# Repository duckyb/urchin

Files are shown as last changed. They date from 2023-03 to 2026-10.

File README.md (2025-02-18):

# Urchin 🪸

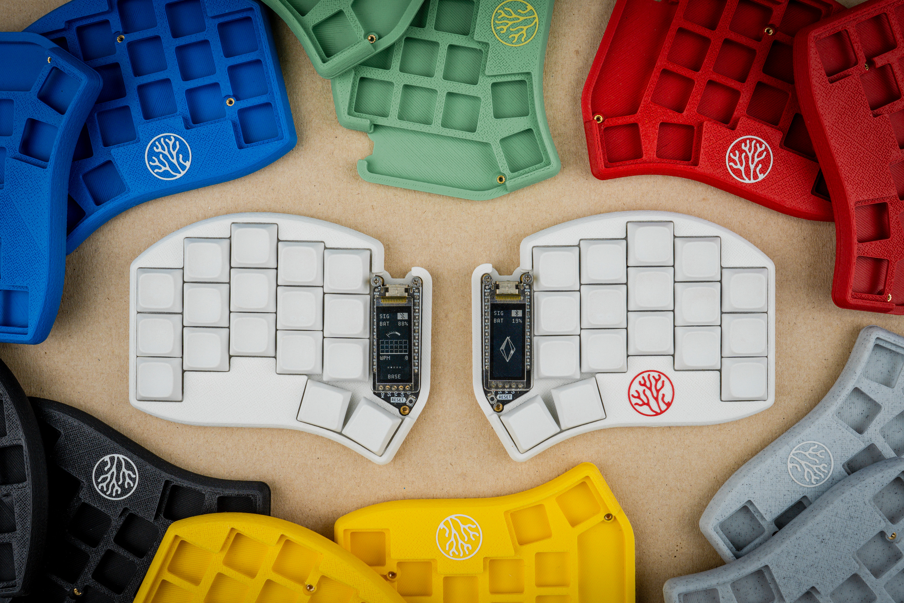
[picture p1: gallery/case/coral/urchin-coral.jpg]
Showcase Picture


<span>
  
  <a href="https://github.com/duckyb/urchin/releases">
    
    
  </a>
  
  <br/>
  <a href="https://discord.gg/hAm5QVJrbU">
    
  </a>
</span>

I created this design because I wanted to upgrade my [Sweep](https://github.com/davidphilipbarr/Sweep) with the fancy nice!view displays. I decided to use the edge design from the [Swoop](https://github.com/jimmerricks/swoop) and to make it compatible with Kailh hotswap sockets.
**This is a strictly wireless-only design, and is only compatible with ZMK / nice!nano. Only Choc v1 switches + Hotswap are supported!**

> Q: Why is this not just another Sweep?
> _A: In order to support the nice!view display I had to use a switch matrix with diodes instead of the Sweep's direct pin design. This means that the firmwares are not interchangeable. I also wanted to use a different PCB shape which makes it incompatible with Sweep cases._

**If you enjoy my work, please consider ⭐ starring and/or ❤ sponsoring it.**

## Sponsors

_Support the people that support me!_ 🙏🏻

<span class="sponsors">
  <a href="https://www.pcbway.com/">
    
  </a>
  <a href="https://shop.beekeeb.com/">
    
  </a>
</span>

## Features

- [x] Design fully optimized for wireless
- [x] Native nice!view support
- [x] Familiar Ferris/Sweep layout
- [x] Improved outline shape
- [x] Support for Kailh hotswap sockets
- [x] Mounting points for cases
- [x] 3D printable enclosure case
- [x] Switch Plate files (3 options)
- [x] MCU/Screen Cover files

## Part list (for a full keyboard)

#### Required

- 1× PCB Kit (files for it are in [releases](https://github.com/duckyb/urchin/releases))
- 34× Kailh **CHOC** Hotswap Sockets
- 34× Kailh Choc v1 Switches
- 34× Keycaps
- 34× SMD diodes (SOD-123)
- 2× nice!nano
- 2× Lipo battery (301230)
- 48× mill-max machined pins
- 2× Pair of female headers

#### Optional

- 2× nice!view
- 2× Reset switch (B3U-1000P(M))
- 2× Power switch (MSK 12C02)
- 10× adhesive silicone feet

#### Case (NEW!)

| Coral Case | Description |
| --- | --- |
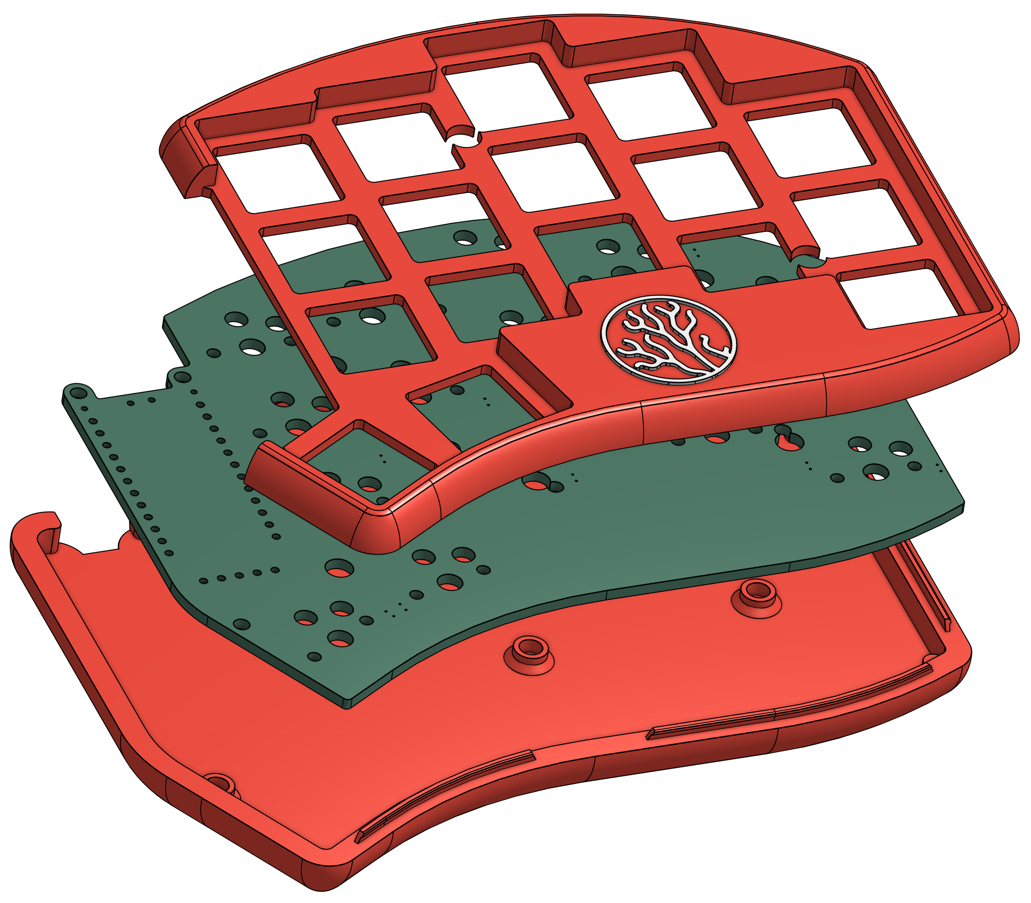
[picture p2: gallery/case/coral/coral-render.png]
Coral Case
|  | The official Coral case is available on [Makerworld](https://makerworld.com/en/models/1057239#profileId-1044921) (for free). Other cases can be found in this repository inside the `3d-prints` folder. |

> [!NOTE]  
> Installing a case, microcontroller cover, or screen acrylic cover will require additional M2 hardware not included in this list. (Like screws, standoffs, nuts, heat set inserts)

## How do I make this?

<a href="https://youtu.be/CHSh1-dJq24" target="_blank">

</a>

## Firmware

Urchin supports ZMK only. To get started with ZMK visit the [zmk-urchin repository](https://github.com/duckyb/zmk-urchin) and follow the provided instructions.

## More videos about Urchin

- https://www.youtube.com/watch?v=o2W_uG-OBjk

## Credits

- PCB edge design by [jimmerricks](https://github.com/jimmerricks/swoop)
- Coral, rocks, sand & bubbles by [Kneecrust](https://linktr.ee/kneecrust)
- The development name "Swipe Light" by [Pete](https://github.com/petejohanson)
- Nice!view integration reference: [sadekbaroudi/sweep36](https://github.com/sadekbaroudi/sweep36)
- ZMK Firmware help by [Mabroum](https://github.com/AlaaSaadAbdo) & [Bravekarma](https://github.com/caksoylar)
- Silkscreen labels style: [bastardkb/dilemma](https://github.com/Bastardkb/Dilemma)
- 3d case by [iamDrakkir](https://github.com/iamDrakkir)
- 3d case by [chewiedies](https://www.printables.com/it/social/360738-chewiedies/about)
- 3d case by [carrefinho](https://github.com/carrefinho)
- Coral logo idea by exosr on discord

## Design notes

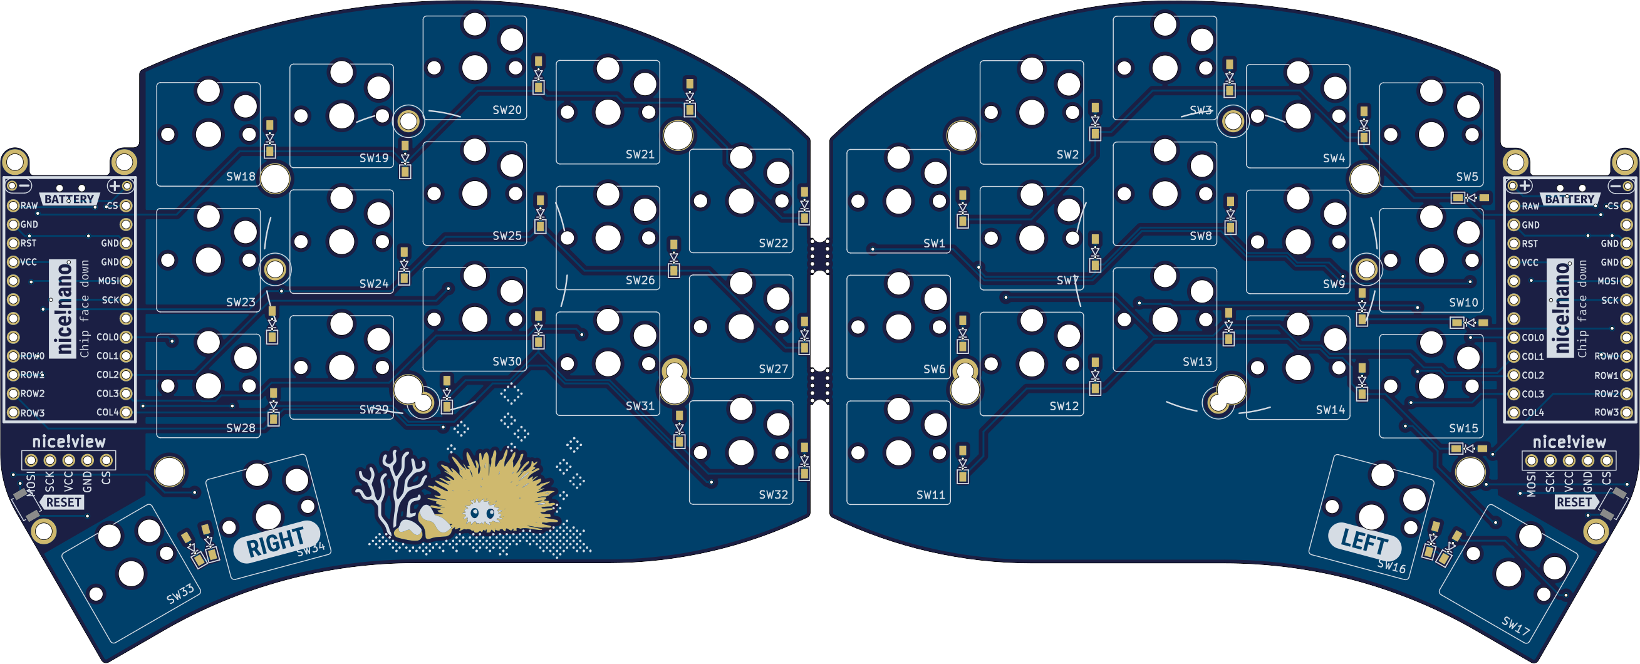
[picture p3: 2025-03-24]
gallery/main/main-top.png

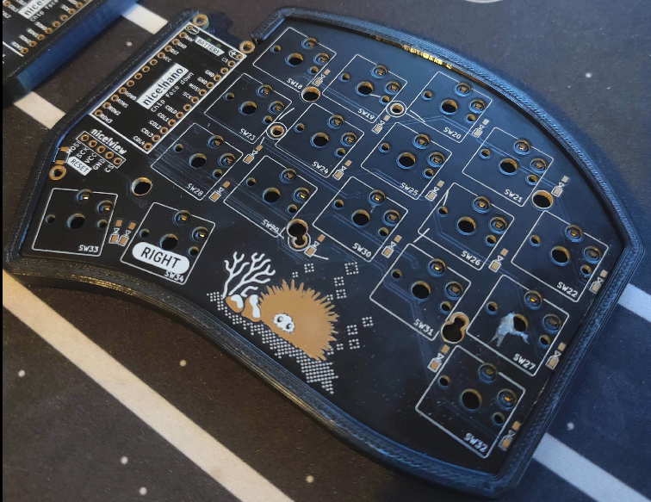
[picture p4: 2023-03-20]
gallery/case/iamDrakkir/rl-side.png

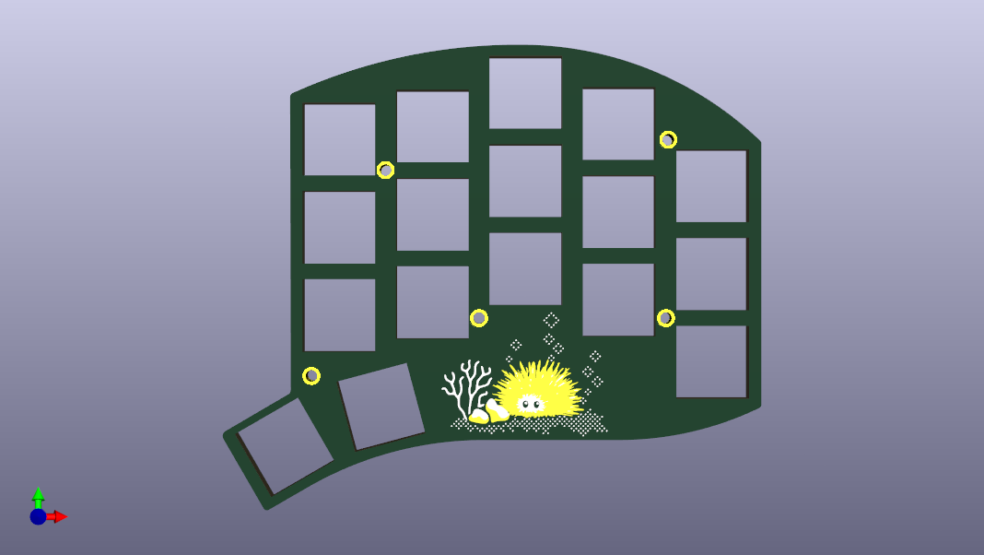
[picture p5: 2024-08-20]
gallery/plate/switch-plate.png

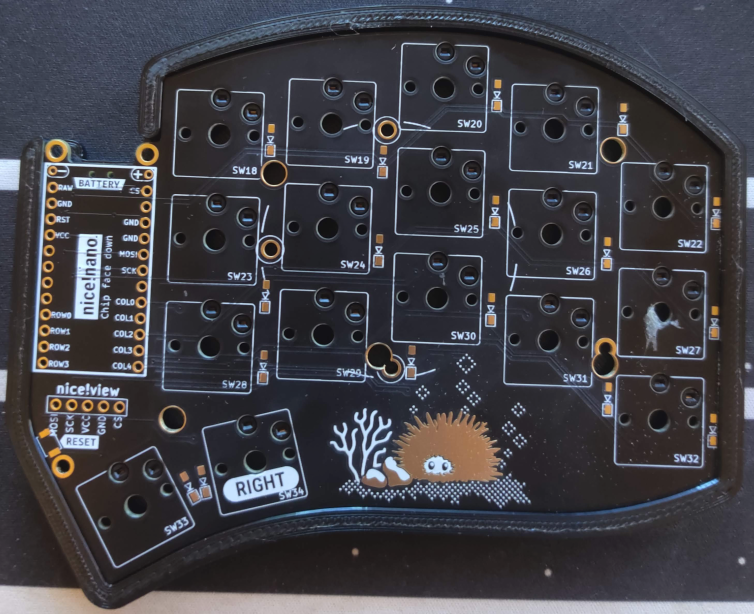
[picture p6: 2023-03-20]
gallery/case/iamDrakkir/rl-top.png

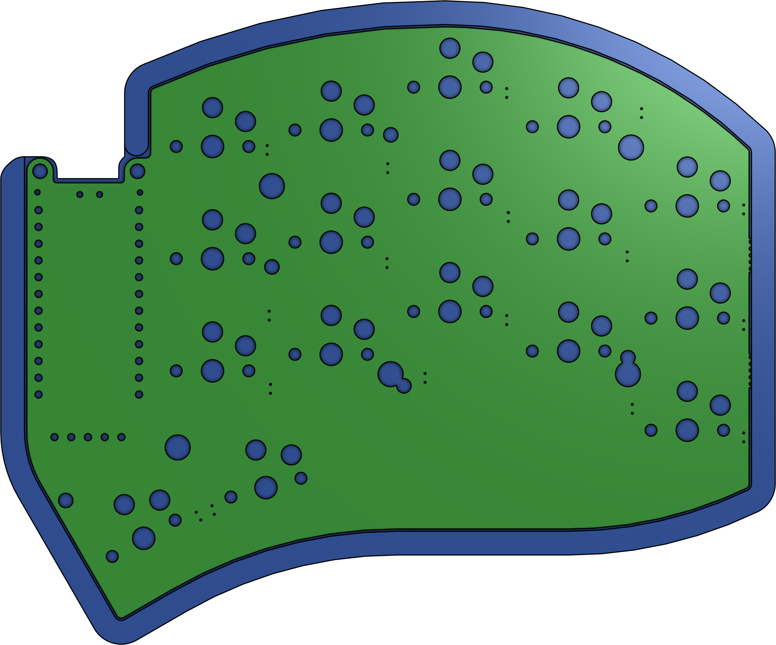
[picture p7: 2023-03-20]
gallery/case/iamDrakkir/cad-top-pcb.png

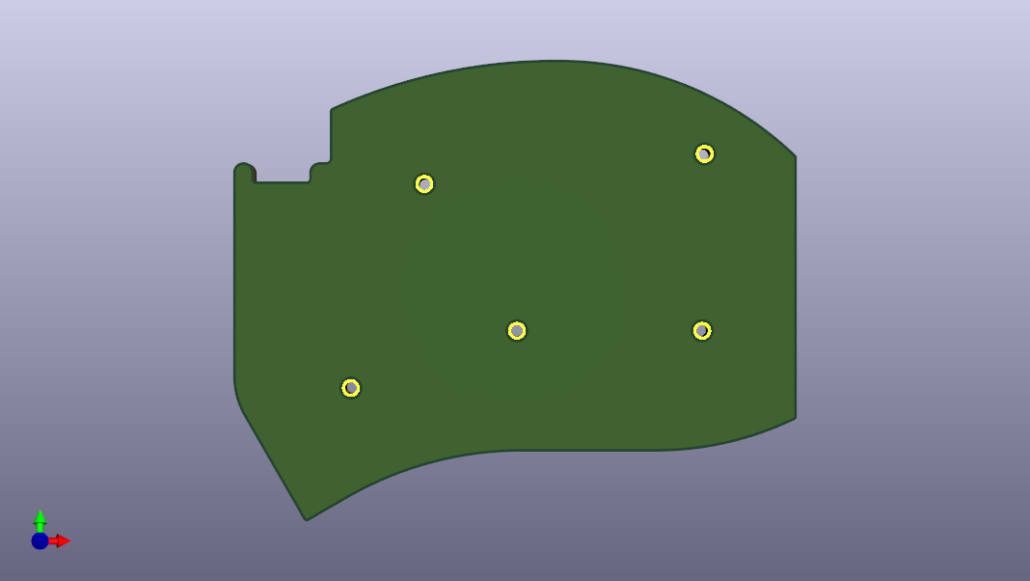
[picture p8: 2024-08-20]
gallery/plate/base-plate.png

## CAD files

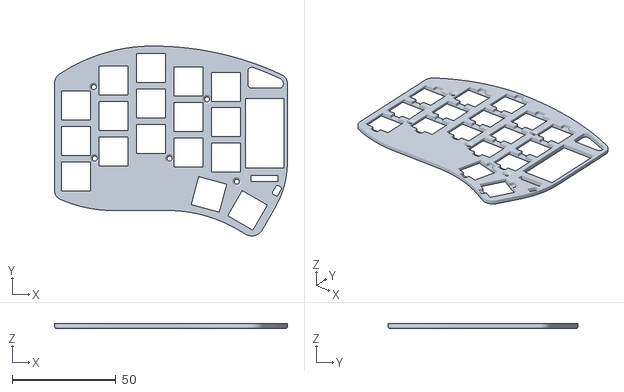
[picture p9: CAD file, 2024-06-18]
3d-prints/case-by-carrefino/urchin_plate_left_full.stl
112.0 x 91.3 x 2.20

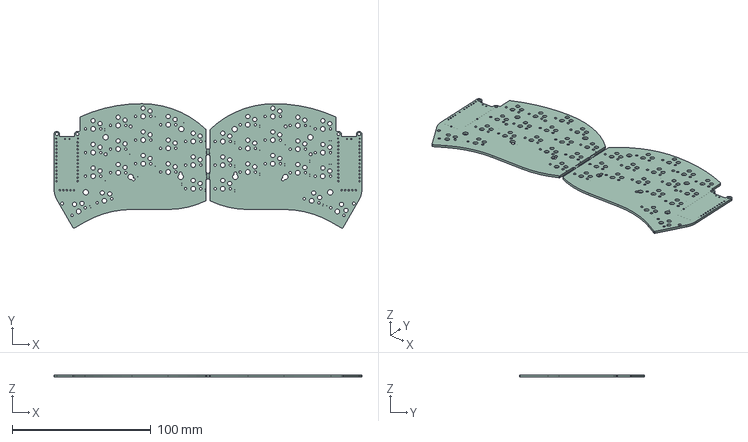
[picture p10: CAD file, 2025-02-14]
main.step
221.6 x 89.6 x 1.60 mm

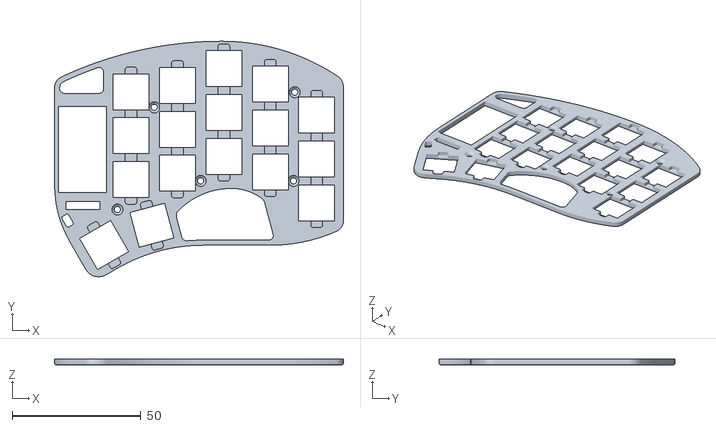
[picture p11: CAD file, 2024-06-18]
3d-prints/case-by-carrefino/urchin_plate_right_full.stl
112.0 x 91.3 x 2.20

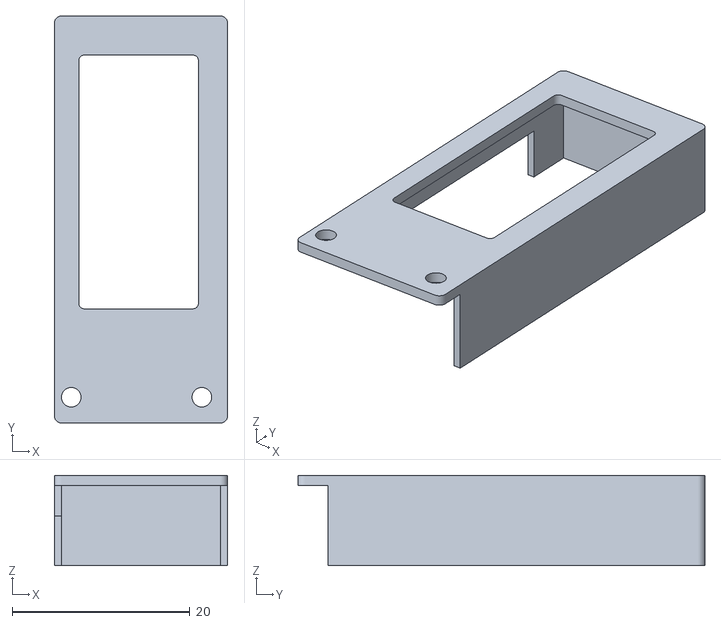
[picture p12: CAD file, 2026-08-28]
3d-prints/boxy-case-by-rayreside/urchin_boxy_shield_right.stl
19.5 x 45.8 x 10.2

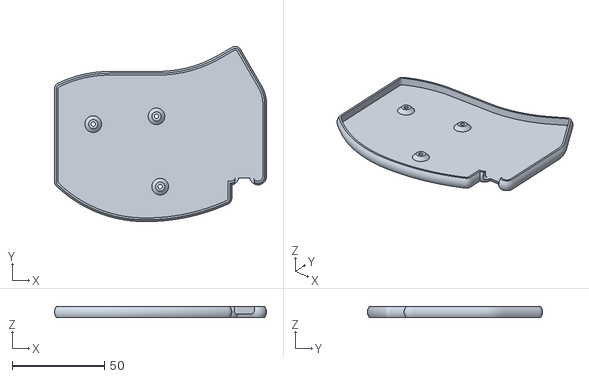
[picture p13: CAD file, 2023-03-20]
3d-prints/case-by-chewiedies/v1-TrayWithFillet-capture.stl
114.7 x 94.8 x 6.00

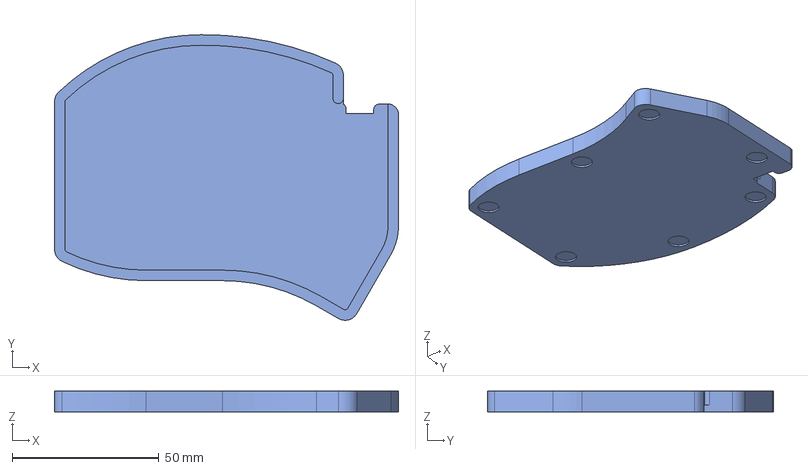
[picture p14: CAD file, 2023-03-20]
3d-prints/case-by-iamDrakkir/case-right.step
117.3 x 97.4 x 7.00 mm

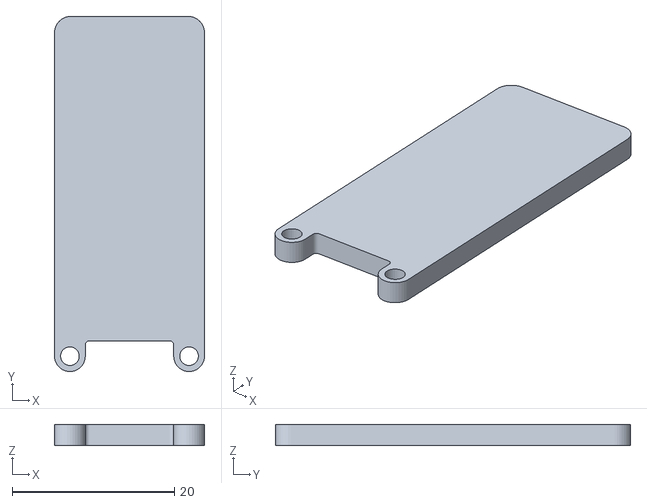
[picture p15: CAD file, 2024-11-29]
3d-prints/screen-shield/screen-shield.stl
18.5 x 43.8 x 2.60

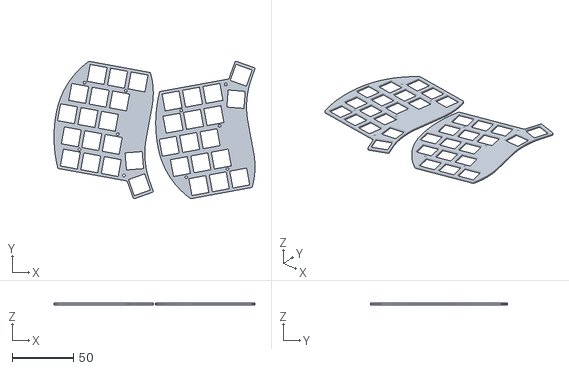
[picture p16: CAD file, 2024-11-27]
3d-prints/switch-plate/standard__plate.stl
164.3 x 112.3 x 1.60

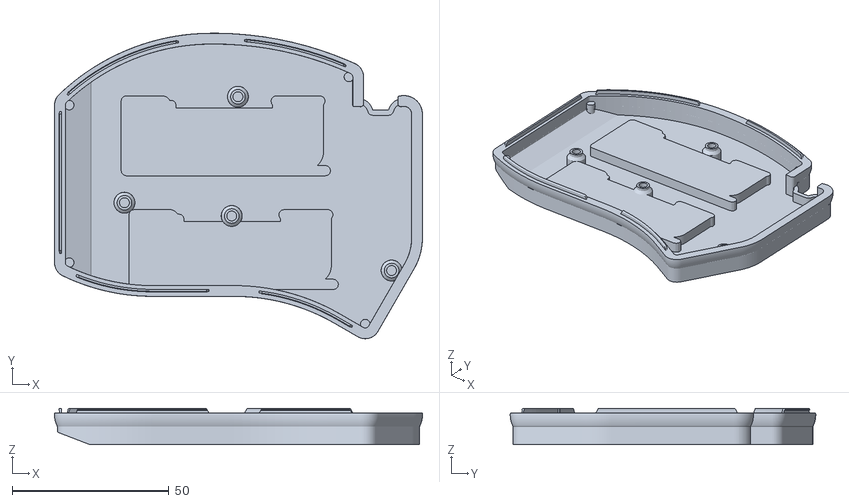
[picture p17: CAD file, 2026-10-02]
3d-prints/tenting-bottom-by-jadefalkner/urchin_tenting_bottom_left.stl
117.4 x 97.5 x 11.5

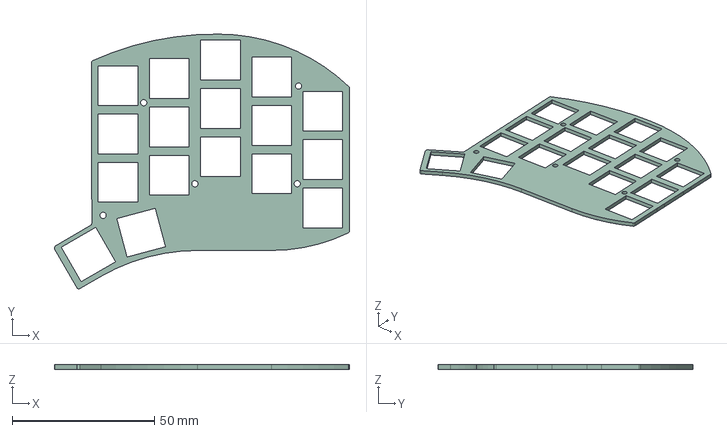
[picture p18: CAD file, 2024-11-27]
plate-case/switch-plate/switch-plate.step
103.7 x 89.6 x 1.60 mm

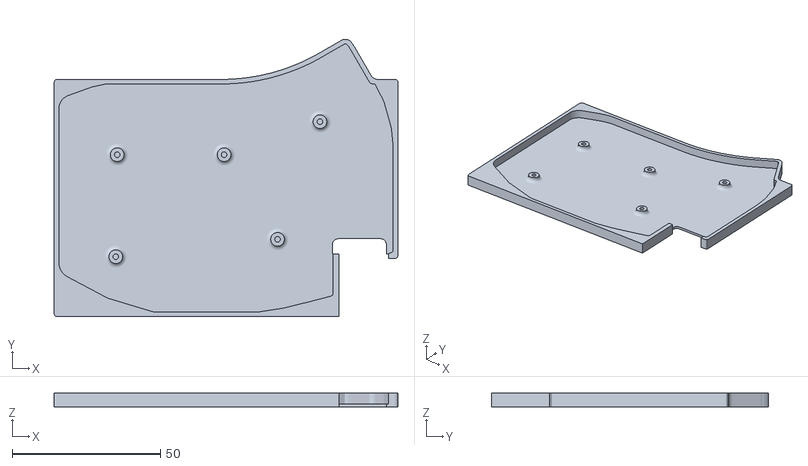
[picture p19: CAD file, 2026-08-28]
3d-prints/boxy-case-by-rayreside/urchin_boxy_bottom_right.stl
115.8 x 93.4 x 4.60

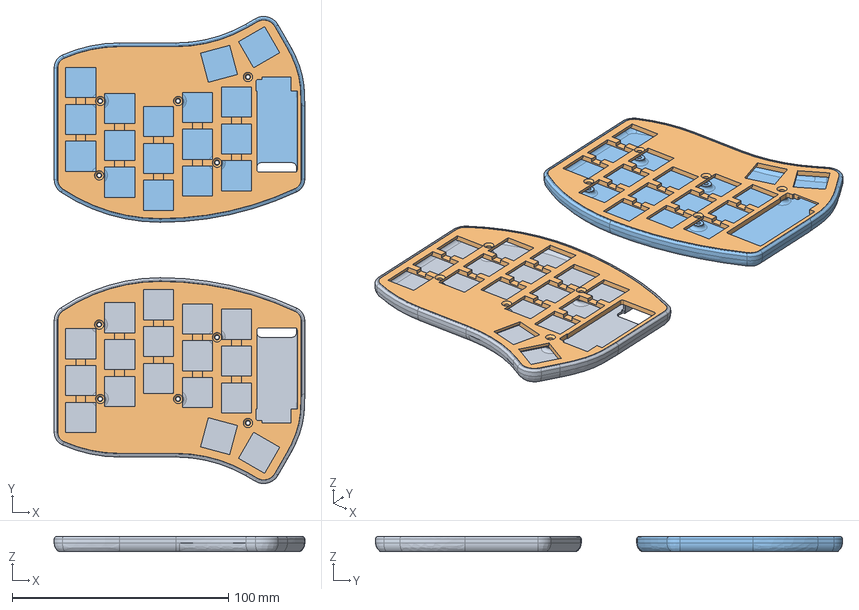
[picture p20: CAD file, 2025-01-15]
3d-prints/case-by-rayreside/case v8.step
115.8 x 215.8 x 6.80 mm

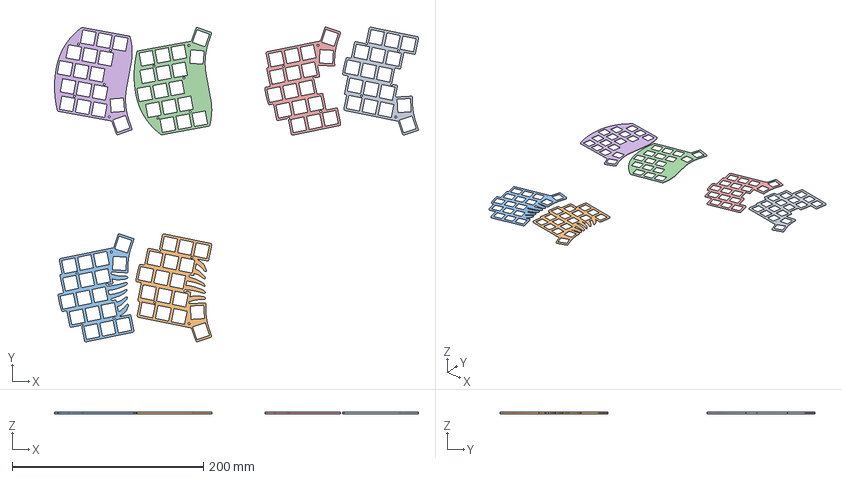
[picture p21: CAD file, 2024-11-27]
3d-prints/switch-plate/ALL-OPTIONS.3mf
380.3 x 329.0 x 1.60 mm
urchin-switch-plate.stl x 4
switch-plate.step x 2

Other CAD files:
3d-prints/case-by-rayreside/screen-shield v16.step
3d-prints/case-by-carrefino/urchin_plate_right_reset.stl
3d-prints/case-by-chewiedies/v1-TrayWithFillet-inserts.stl
3d-prints/case-by-iamDrakkir/case-left.step
3d-prints/tenting-bottom-by-jadefalkner/urchin_tenting_bottom_right.stl
3d-prints/boxy-case-by-rayreside/urchin_boxy_mountains_right.stl
3d-prints/boxy-case-by-rayreside/urchin_boxy_top_right.stl
3d-prints/case-by-carrefino/Urchin Plate Case.f3z
3d-prints/case-by-carrefino/Urchin Plate Case.step
3d-prints/case-by-carrefino/urchin_case_left.stl
3d-prints/case-by-carrefino/urchin_case_right.stl
3d-prints/case-by-carrefino/urchin_plate_left_basic.stl
3d-prints/case-by-carrefino/urchin_plate_left_reset.stl
3d-prints/case-by-carrefino/urchin_plate_right_basic.stl
3d-prints/case-by-chewiedies/Urchin_Tray_Case.f3d
3d-prints/case-by-chewiedies/v1-TrayWithChamfer-capture.stl
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

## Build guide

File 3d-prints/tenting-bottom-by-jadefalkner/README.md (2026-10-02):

# Urchin tenting bottom (TOTEM feet)

A replacement bottom for the official Coral case that takes the same tenting
feet as the TOTEM tenting case (the AliExpress feet from #23). The Coral top
is used unchanged. A 40 × 20 × 4 mm (350 mAh) battery fits next to the feet.

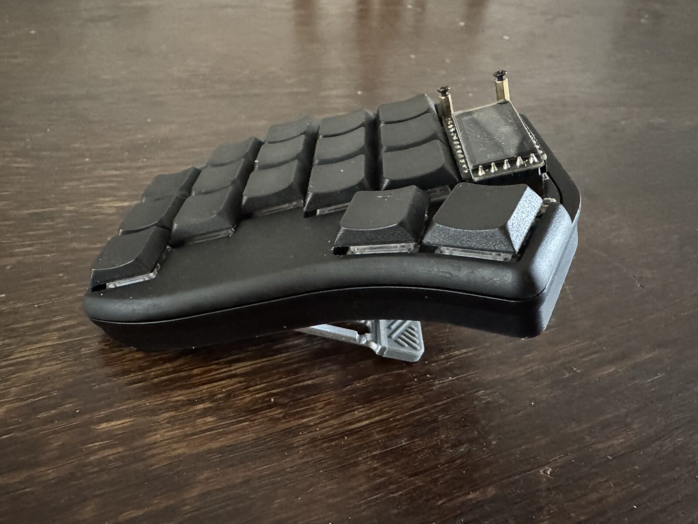
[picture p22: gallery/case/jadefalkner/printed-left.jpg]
Printed left half, tented


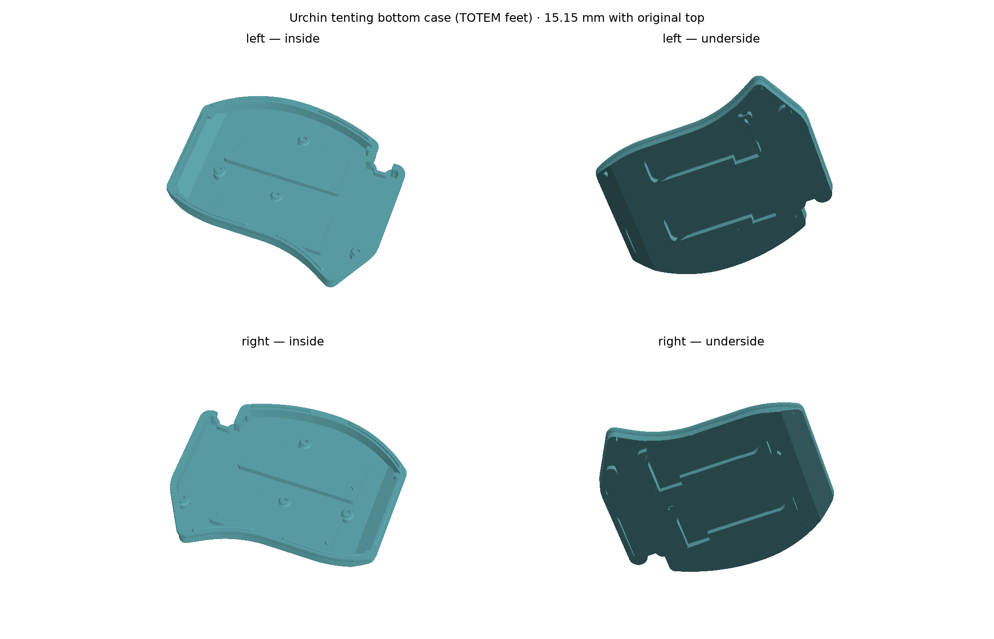
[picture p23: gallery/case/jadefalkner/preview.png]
Tenting bottom, inside and underside


## Parts

- `urchin_tenting_bottom_left.stl`
- `urchin_tenting_bottom_right.stl`

Each half has two foot pockets running east–west, so the halves tent towards
the middle. The right half is a mirror of the left, pockets included.

## Dimensions

- Bottom: 11.53 mm. With the Coral top: 15.15 mm (without feet, switches and keycaps).
- Floor 2 mm. Foot pockets 4.1 mm deep, roofed with 1.65 mm at the height of
  the original inner floor, so the electronics clearance is the same as in the
  original bottom.
- Outer bearing chamfer 21.1° like the TOTEM tenting bottom, 2 mm wall.
- Battery next to the feet: a 40 × 20 × 4 mm (350 mAh) pouch cell is in use
  in the printed revision. Cable and connector routing are not modelled.

## Hardware

- 2× TOTEM-style tenting feet per half
- The same screws as the original Coral case

## Printing

The pictured parts were ordered from JLCPCB as SLA resin (Imagine Black,
sanded) and needed no supports.

On an FDM printer, print floor down as oriented. The only overhangs are the
roofs of the two foot pockets: flat bridges of about 20 mm, 4.1 mm above the
bed. They can be bridged, or you add supports inside the pockets only. The
rest of the part has no overhangs.

## Status

The previous revision of this bottom was printed and fits the Coral top and
the feet. This revision only closes two unintended thin slits next to the foot
pockets and is otherwise identical. It is verified in CAD (watertight, single
solid, manifold after binary STL export) but has not been printed yet.

The geometry is generated parametrically (CadQuery + trimesh) on top of the
original bottom mesh; the build scripts are not part of this repository.

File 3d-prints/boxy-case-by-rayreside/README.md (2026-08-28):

# urchin boxy case

A high-profile case: raised rim, with mountains between the keycaps. Four
printed parts per half, no supports.

Fits both the duckyb and the beekeeb PCB.

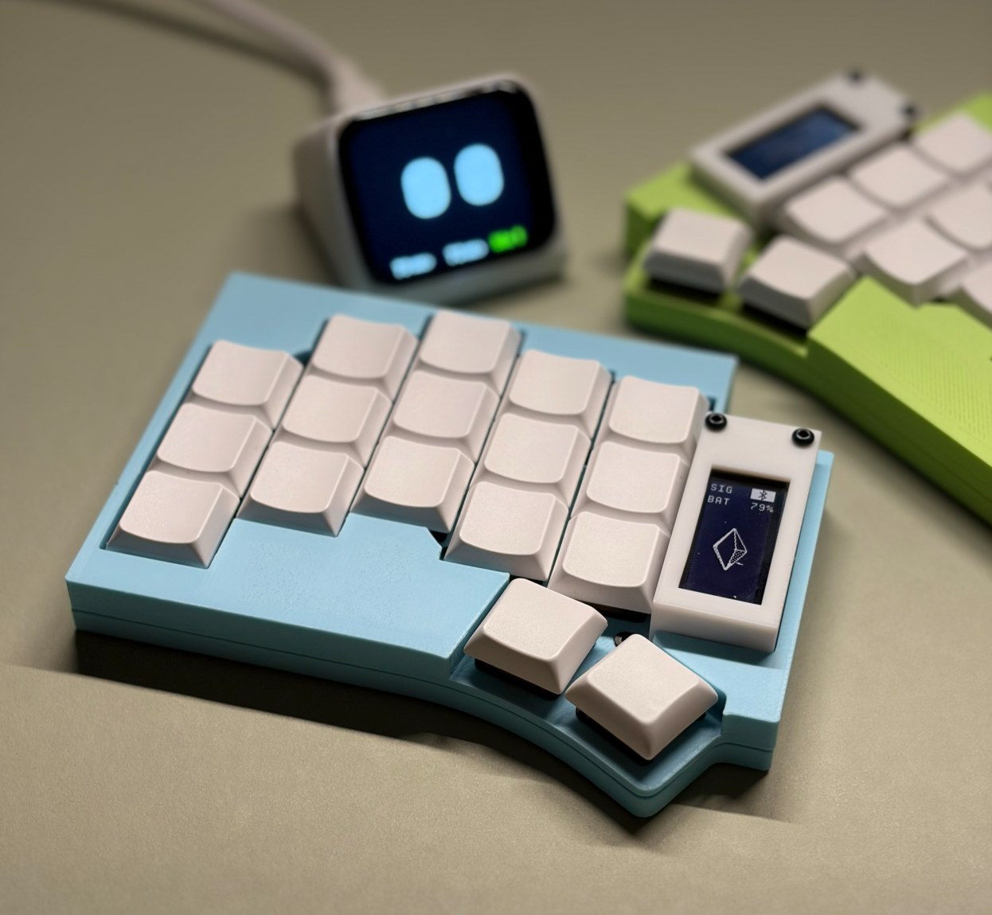
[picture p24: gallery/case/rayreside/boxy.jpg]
Both halves of the boxy case, printed, plus a Prospector dongle


## Parts

- `urchin_boxy_top_right.stl` - switch plate and rim
- `urchin_boxy_mountains_right.stl` - raised pads between the keycaps
- `urchin_boxy_bottom_right.stl` - floor, standoffs and skirt
- `urchin_boxy_shield_right.stl` - screen shield over the MCU

Right half only - mirror in your slicer for the left. Mirror the top and the
mountains together, they share coordinates.

Assembled height is 11.88 mm.

## Printing

Print as oriented, no supports on any part: top on its plate underside, bottom
floor down, shield flat face down.

Load the mountains as a *part of the top*, not as a separate object - they span
z 3.8 to 8.88 and float if imported alone. In Bambu Studio: import the top,
then right-click it -> Add part -> Load and pick the mountains. They share
coordinates and align on import.

## Notes

On a beekeeb board there is no room for the JST socket under the plate. Remove
it and solder the battery to the pads directly. duckyb's design assumes direct
soldering, so it doesn't have this problem.

The plate is cut through over the duckyb reset button so it isn't held
down, but the button is not reachable - the mountains roof the hole.
Resetting means taking the top off.

The screen shield mounts on metal standoffs, not printed ones.

## Source

Built from OpenSCAD source at
[urchin-cuboid-case](https://github.com/rayreside/urchin-cuboid-case), MIT.

The raised rim and mountains form is inspired by [TOTEM](https://github.com/GEIGEIGEIST/TOTEM)
by GEIGEIGEIST and [Karma](https://github.com/achyudh/karma) by achyudh.

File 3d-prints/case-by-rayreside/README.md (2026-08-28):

# urchin-case

This requires the beekeeb version of the urchin keyboard.

The battery would have to be soldered directly and put underneath the MCU, and the JST socket needs to be taken off.

No need to desolder the JST socket if you don't have a desoldering pump, I pried off mine and adjusted the case design to have some room for the remaining bits that I couldn't personally completely take off.

Please note that the screen shield hides the reset button completely.

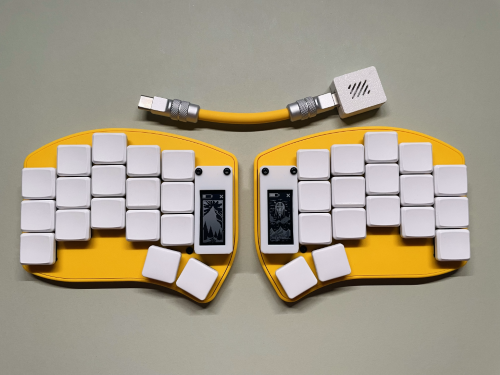
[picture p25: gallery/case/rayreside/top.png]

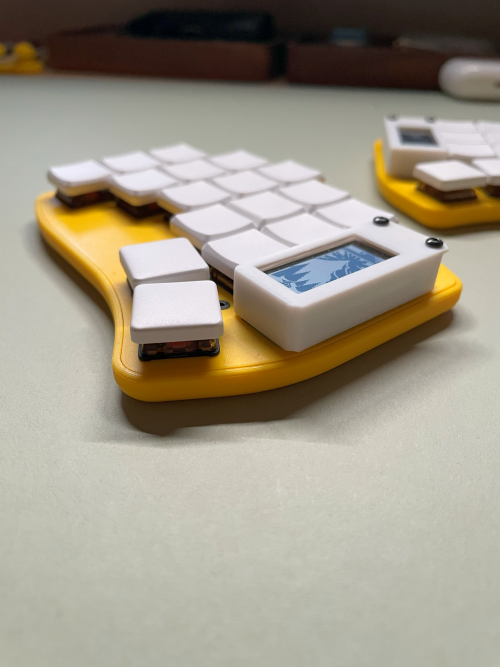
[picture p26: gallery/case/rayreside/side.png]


There is also a high-profile version of this case in
[boxy-case-by-rayreside](../boxy-case-by-rayreside).

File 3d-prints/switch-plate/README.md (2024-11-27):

<!-- Table displaying the options for the switch plate -->
| Standard | Skeleton | FishBone |
| --- | --- | --- |
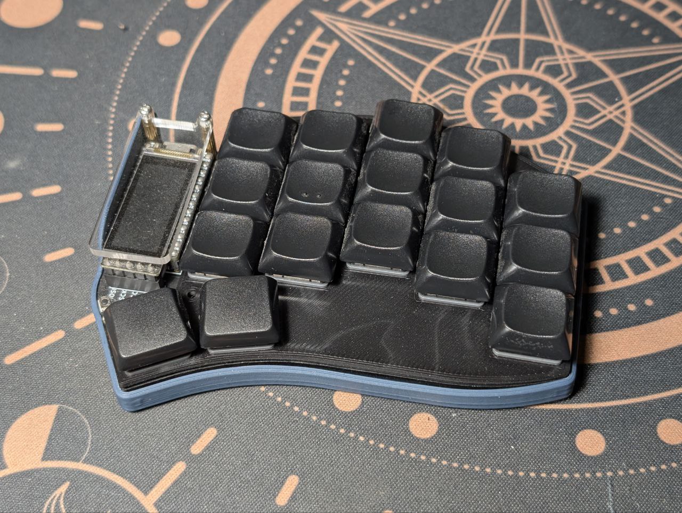
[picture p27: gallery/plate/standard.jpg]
Standard
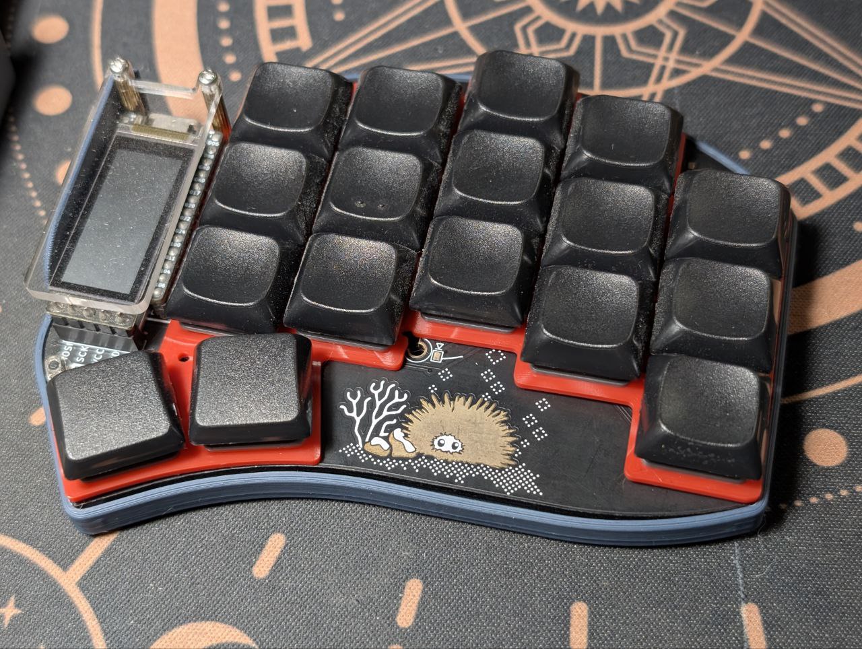
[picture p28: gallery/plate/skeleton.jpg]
Skeleton
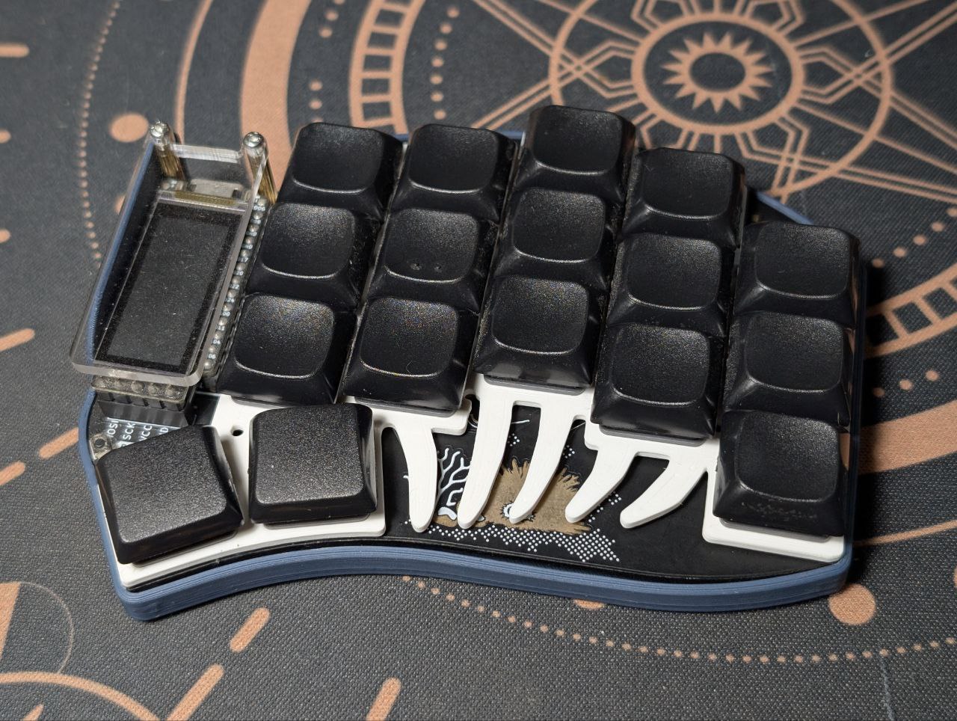
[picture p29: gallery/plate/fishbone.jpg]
FishBone
|  |  |  |

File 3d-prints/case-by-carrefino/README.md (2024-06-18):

# Urchin Plate Case #

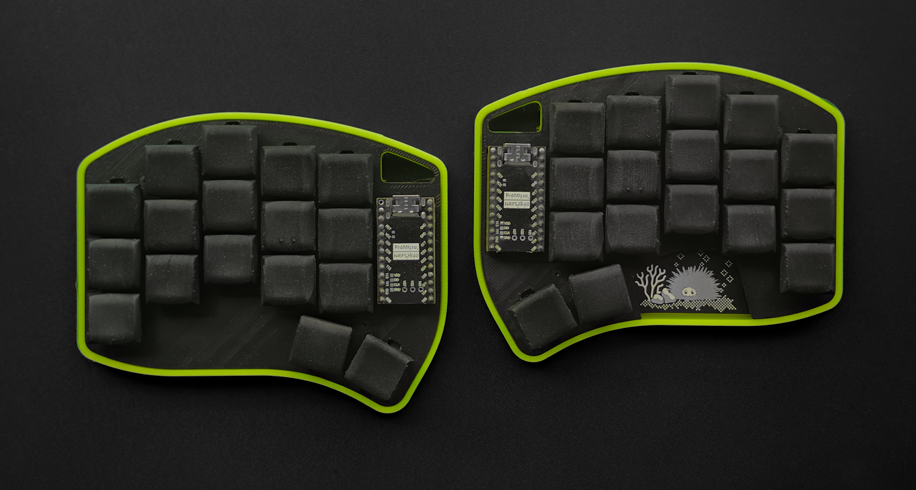
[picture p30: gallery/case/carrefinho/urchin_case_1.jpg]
urchin in fluorescent yellow


## Plate Versions ##

*Only Basic version was tested for fit, others are designed with CAD models only.*

- Basic
  - cutout for controller (pictured above)
- Reset
  - cutouts for controller and reset button
- Full
  - cutouts for controller, reset button, and nice!view display

## Hardware ##

- 10x M2 Countersunk Screws (total length of 5-6mm)
  - screws directly into plastic so probably don't take it apart too often

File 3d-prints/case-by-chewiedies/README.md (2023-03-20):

## Version differences

- Fillet: the outer edge of the case has a fillet finish
- Chamfer: the outer edge of the case has a chamfer finish
- Capture: the case has a hole to hold a small nut to secure the pcb with M2 screws
- Inserts: the case has a hole where you can melt a heat-insert to secure the pcb with M2 screws

> **Note**
> Capture is optimized for resin prints, inserts is optimized for FDM.

The outer diameter of the hole **in the inserts model** is `3.4mm` and the depth is `3.76mm`

## Preview

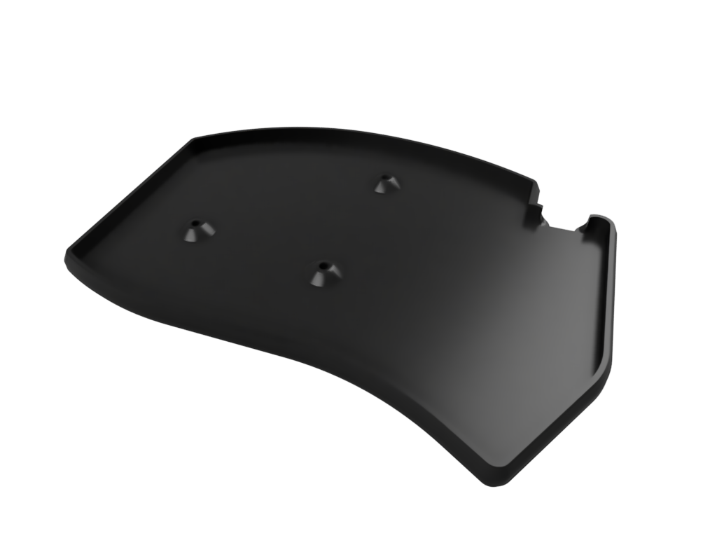
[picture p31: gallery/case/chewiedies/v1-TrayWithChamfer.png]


## Known Issues

- This design provides a single part that needs to be mirrored in the slicer software to print the left side. However, there are very slight misalignments bewteen the two PCBs that cause the screw holes to be *slightly* off-center. The design is still functional and all screws can be mounted.
- The cutout for the power switch isn't big enough to reach the switch comfortably. This could be improved but it's still very usable.
- When using a very low infill value, the curved bottom wall of the fillet case is weak. Printing at a higher infill is recommended.

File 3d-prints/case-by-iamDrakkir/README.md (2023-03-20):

No additional hardware required.

> **Warning** 
> This tray case doesn't have a mounting system, the keyboard will just rest inside it without being secured to it.

## Preview

| Top | Side |
| --- | --- |
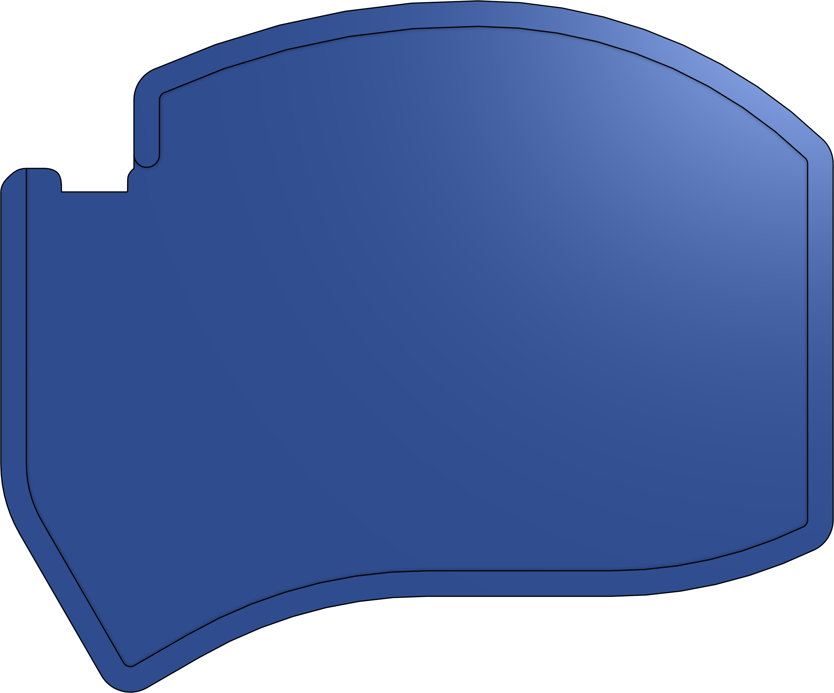
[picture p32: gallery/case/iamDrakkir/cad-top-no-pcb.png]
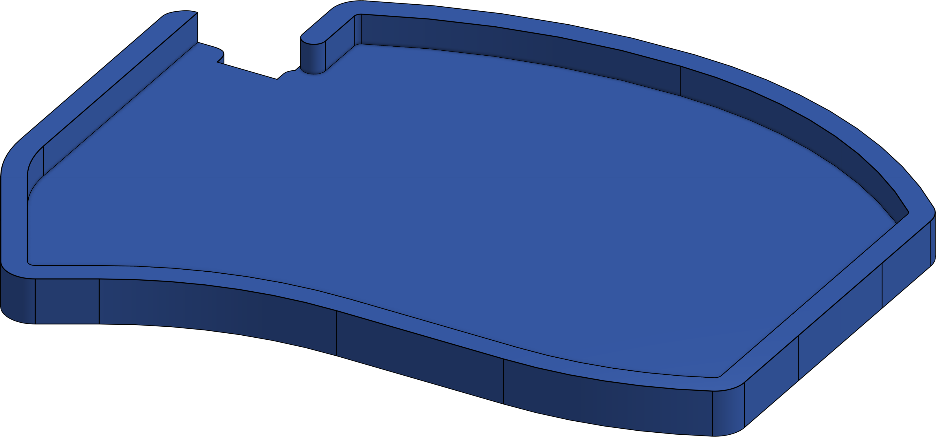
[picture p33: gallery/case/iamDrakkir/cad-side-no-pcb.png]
|  |  |

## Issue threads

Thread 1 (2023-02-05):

choc v1 and cherry MX

dhruvinsh, 2023-02-05:
Hi,
Is it possible to accommodate both switch types like Sweep does. I am looking for cherry MX along with choc v1 if possible.

duckyb, 2023-02-05:
@dhruvinsh Sorry but this is currently out of the scope of this project. Adding support for more switches would make the repository and PCB much more complex and it's not something I'm interested in for the Urchin.

If you wish to add support for them yourself feel free to fork the repository and make the changes, I can give some advice if needed.

dhruvinsh, 2023-02-06:
Make sense. Thank you. What is the best way to reach out to you? Are you available on discord?

duckyb, 2023-02-06:
Yes you can find me on discord, this is my account:
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

dhruvinsh, 2023-02-06:
Thanks. Just send you a request.

Closed 2023-02-05.

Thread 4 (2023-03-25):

Footprint '* duckyb-collection:***' not found

Wesztman, 2023-03-25:
Hi! Love your work here <3 I have the Sweep myself and wanted to build a Urchin as well, but as my first ever keyboard modification I'm trying to make it a 40 key layout as I saw you had 3 missing keys in the matrix 😊

- One more thumb key
- One more column with two pinky keys

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

Now I should say that I'm a full blown KiCAD noob, but I'm getting errors that I believe indicates that I'm missing a library. Is this something you have shared somewhere? 😇

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

duckyb, 2023-03-25:
This is not really a problem, it's just kicad letting you know that it's missing the footprint library that I used. However the footprints on the PCB still load correctly so it doesn't cause any real issues.

However I took the time to export all of the footprints into a new library that is now included with the project.
If you pull the changes I just made the error should go away.

PS. Thank you so much for the donation! 🍻

Wesztman, 2023-03-25:
Awsome! Worked perfectly! Thanks! 😁😁

Closed 2023-03-25.

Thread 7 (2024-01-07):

wired version?

lpanebr, 2024-01-07:
Any chance of my getting a wired version?
Thanks!

duckyb, 2024-01-07:
I'm not interested in providing a wired version, but anyone is welcome to fork this project. If you want a wired build I'd recommend the Sweep instead.

duckyb, 2025-03-24:
Note:

Keep in mind that the keyboard can be used wired, even without a battery. But the two halves of the keyboard communicate via bluetooth only.

Adding a wired connection between the two halves (wired interconnect) is not supported by ZMK. But even if it was, I am not willing to develop and maintain two different versions of this keyboard.

Closed 2024-01-07.

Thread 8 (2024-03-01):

Remove diode footprint from the top surface

ToppDev, 2024-03-01:
Following up on the comment in PR #5, I think this is better to discuss in an Issue first.

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

With removing the Diods on the top side, do you mean something like what was done in #6? (the right through hole could also be removed I think)
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

If you are interested, I could start fresh from the current main and replace the diods. Result would look something like

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

duckyb, 2024-03-02:
If it's done correctly in #6 I can just merge that. I just didn't make time to review it yet, that's my bad.
I have to setup kicad from scratch so I've been delaying it.

ToppDev, 2024-03-02:
@Mathrocker666 sadly deleted his branch already. If he is still around and could reopen his PR that would be nice

duckyb, 2024-03-02:
Restored in #9

Closed 2024-03-14.

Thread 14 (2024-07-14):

Updated Release?

markuskobler, 2024-07-14:
Is it possible to build/release the updated PCB?

Not having used kicad before it looks like I need an older version and its not very clear how to safely create a gerber file.

markuskobler, 2024-07-14:
I think I figured it out by switching to the develop branch and downgrading to the previous release of kicad

Closed 2024-07-14.

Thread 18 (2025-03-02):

Release the Coral case here?

WizardUli, 2025-03-02:
Would you consider releasing the Coral case here in addition to that login-only Chinese owned site? Or at least on some page which does not require signing some terms of use when you just want to download it like https://printables.com ? Thanks.

duckyb, 2025-03-03:
I released it on makerworld because I am enrolled in their point system that gives me a monetary reward without any cost to the users (even just downloading the file from there helps me). The model is a makerworld exclusive so I can't just mirror it to other websites.

However you can email me or message me on discord and I can provide you with a file if you wish to bypass the use of makerworld.

WizardUli, 2025-03-03:
Ah, that's understandable then. Thank you for your answer!

duckyb, 2025-03-03:
Thank you for the donation @WizardUli 🙏🏻 ✨

Closed 2025-03-03.

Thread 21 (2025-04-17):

Battery capacity

timsofteng, 2025-04-17:
Hello.
Sorry for new issue. It's a question but there is no discussion in repo. Feel free to redirect me to more appropriate place  please if so.

Is it possible to install baterry with more capacity than 110mah?
I'm afraid it drains pretty fast.

duckyb, 2025-04-18:
Yes you can install pretty much any battery you want. The problem will be finding a place where to put it.
I recommend the 110mAh Lipo battery because it fits under the nice!nano and is hidden away.

You can have a look at this tool to estimate how long the keyboard will last: https://zmk.dev/power-profiler

timsofteng, 2025-04-18:
Thank you! Do you think 200mah will not fit?

duckyb, 2025-04-20:
I think 110mAh is the limit

Closed 2025-04-22.

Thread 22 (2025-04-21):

ph 2.0 plug for battery

brancz, 2025-04-21:
The beekeeb version of the urchin seems to have removed the power switch in favor of the ph 2.0mm connector. Having replaced a battery before it would be nice if it wasn't soldered onto the PCB directly. At the same time, I wouldn't want to give up the power switch either.

1) Would you consider adding a ph 2.0 mm connector?
2) If so, where do you think on the PCB it could go?

duckyb, 2025-04-22:
I think the only available spot is where Beekeeb added it, south of the MCU

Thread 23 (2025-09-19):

Create a bottom case that uses the same feets as the totem tenting case

Jadefalkner, 2025-09-19:
Please create a case that uses a similar layout to

https://github.com/GEIGEIGEIST/TOTEM/blob/main/docs/images/TOTEM_case_tenting_bottom.png?raw=true

maybe that would make room for a bigger battery inside the case too.

Regards.

duckyb, 2025-09-19:
These are the ones I have: https://aliexpress.com/item/1005007508346709.html

I already tried to do that, because I am using those tenting feet, but with the current design there is not enough space to fit them. I need to tweak the case to have a larger bottom surface to create space for them.
It's something I eventually would like to do but I can't promise that I'll do it soon.

Jadefalkner, 2025-09-19:
yes, those are exactly the same as for the totem, so the dimensions should work fine

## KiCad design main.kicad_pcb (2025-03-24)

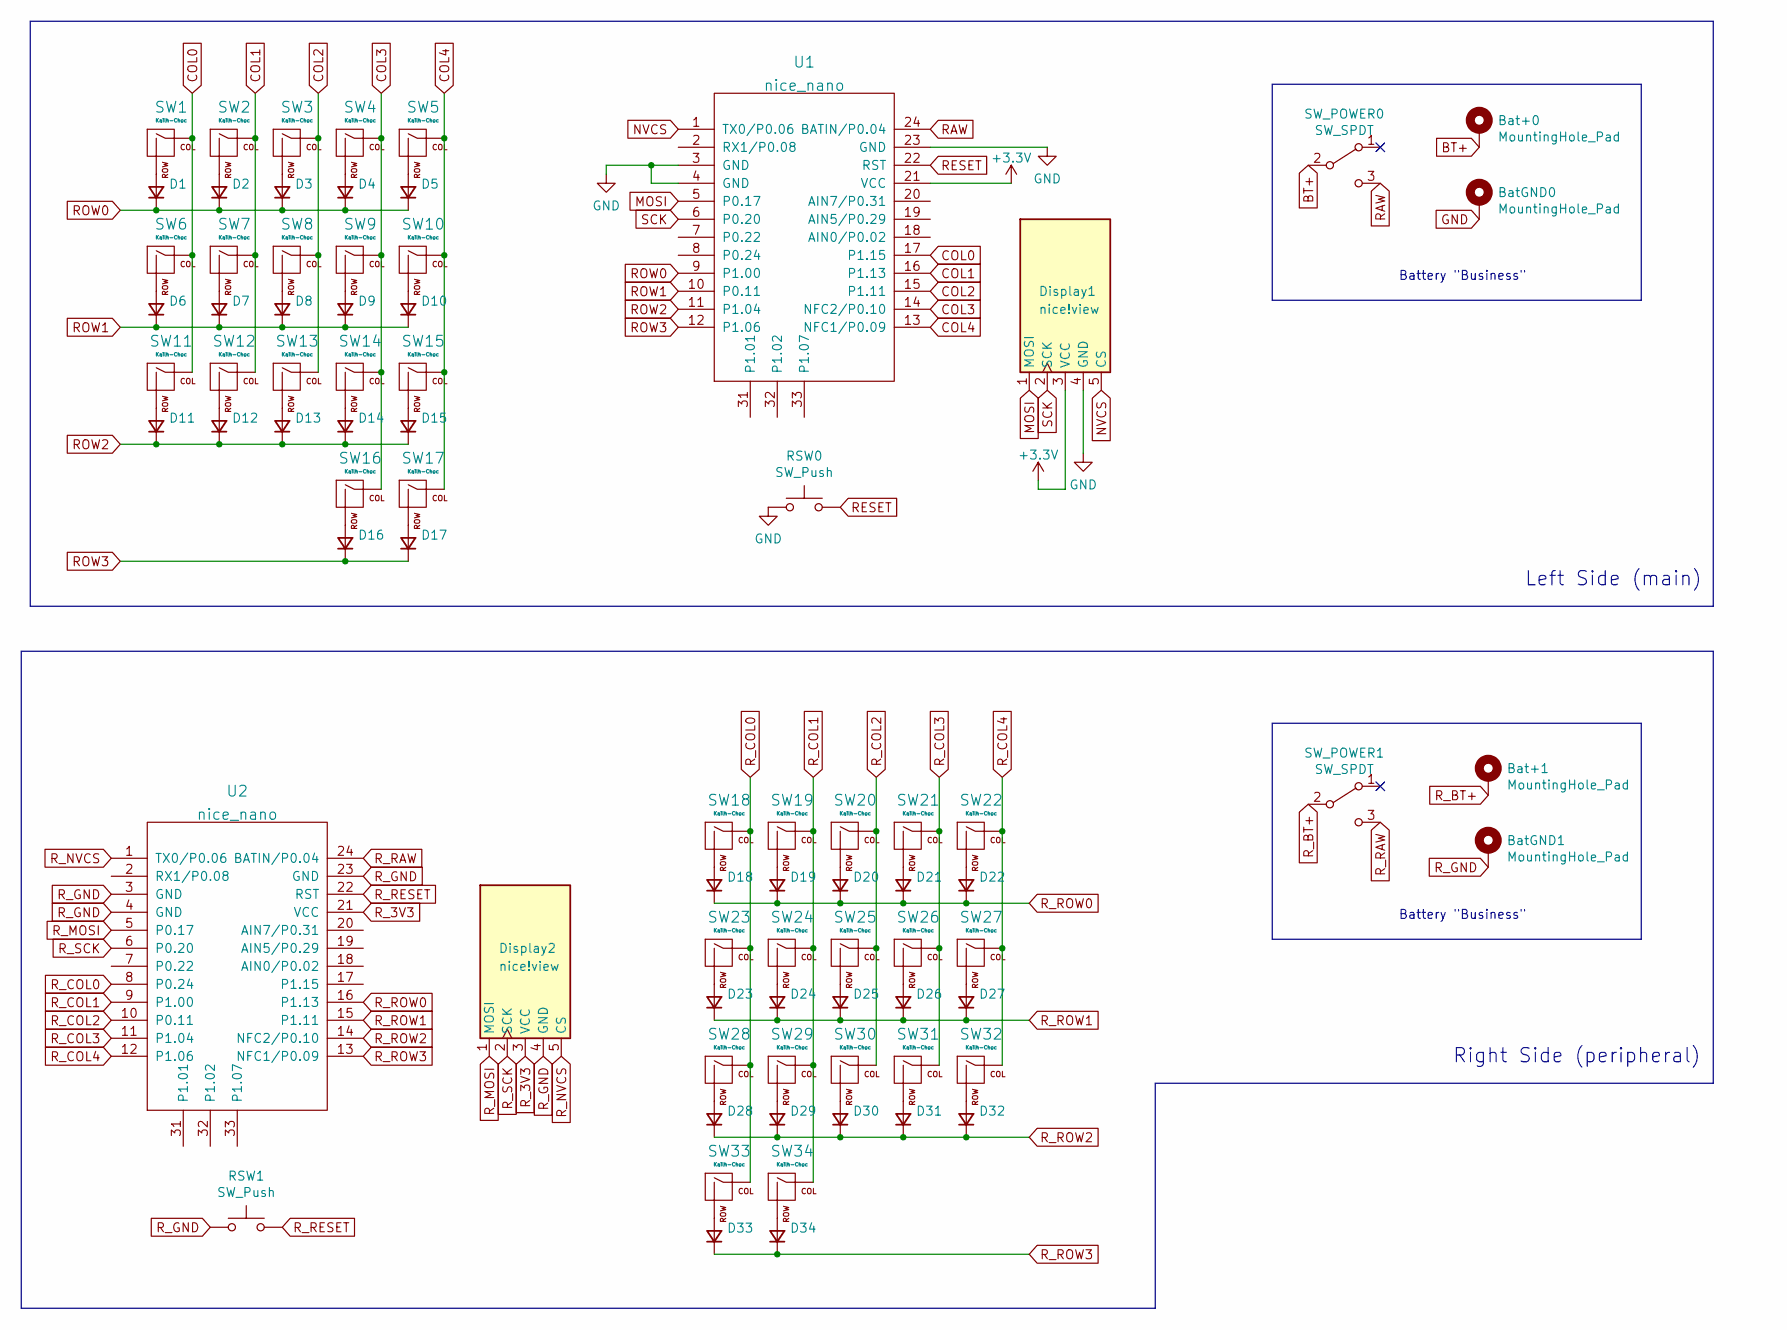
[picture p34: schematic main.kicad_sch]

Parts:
Bat+0, Bat+1: MountingHole_Pad; 1pin_Battery
BatGND0, BatGND1: MountingHole_Pad; 1pin_Battery
D1, D2, D3, D4, D5, D6, D7, D8, D9, D10, D11, D12, D13, D14, D15, D16, D17, D18, D19, D20, D21, D22, D23, D24, D25, D26, D27, D28, D29, D30, D31, D32, D33, D34: diode; SMD_Diode_Tiny
Display1, Display2: nice!view; nice_view
RSW0, RSW1: SW_Push; SW_RESET
SW1, SW2, SW3, SW4, SW5, SW6, SW7, SW8, SW9, SW10, SW11, SW12, SW13, SW14, SW15, SW16, SW17, SW18, SW19, SW20, SW21, SW22, SW23, SW24, SW25, SW26, SW27, SW28, SW29, SW30, SW31, SW32, SW33, SW34: Kailh-Choc; SW_Hotswap_Kailh_Choc_V1_tweaked
SW_POWER0, SW_POWER1: SW_SPDT; smt-slider-switch
U1, U2: nice_nano

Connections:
+3V3: Display1.3 (VCC), U1.21 (VCC)
BT+: Bat+0.1, SW_POWER0.2 (B)
COL0: SW1.1 (COL), SW6.1 (COL), SW11.1 (COL), U1.17 (P1.15)
COL1: SW2.1 (COL), SW7.1 (COL), SW12.1 (COL), U1.16 (P1.13)
COL2: SW3.1 (COL), SW8.1 (COL), SW13.1 (COL), U1.15 (P1.11)
COL3: SW4.1 (COL), SW9.1 (COL), SW14.1 (COL), SW16.1 (COL), U1.14 (NFC2/P0.10)
COL4: SW5.1 (COL), SW10.1 (COL), SW15.1 (COL), SW17.1 (COL), U1.13 (NFC1/P0.09)
GND: BatGND0.1, Display1.4 (GND), RSW0.1, U1.3 (GND), U1.4 (GND), U1.23 (GND)
MOSI: Display1.1 (MOSI), U1.5 (P0.17)
NVCS: Display1.5 (CS), U1.1 (TX0/P0.06)
unnamed: D1.2 (A), SW1.2 (ROW)
unnamed: D2.2 (A), SW2.2 (ROW)
unnamed: D3.2 (A), SW3.2 (ROW)
unnamed: D4.2 (A), SW4.2 (ROW)
unnamed: D5.2 (A), SW5.2 (ROW)
unnamed: D6.2 (A), SW6.2 (ROW)
unnamed: D7.2 (A), SW7.2 (ROW)
unnamed: D8.2 (A), SW8.2 (ROW)
unnamed: D9.2 (A), SW9.2 (ROW)
unnamed: D10.2 (A), SW10.2 (ROW)
unnamed: D11.2 (A), SW11.2 (ROW)
unnamed: D12.2 (A), SW12.2 (ROW)
unnamed: D13.2 (A), SW13.2 (ROW)
unnamed: D14.2 (A), SW14.2 (ROW)
unnamed: D15.2 (A), SW15.2 (ROW)
unnamed: D16.2 (A), SW16.2 (ROW)
unnamed: D17.2 (A), SW17.2 (ROW)
unnamed: D18.2 (A), SW18.2 (ROW)
unnamed: D19.2 (A), SW19.2 (ROW)
unnamed: D20.2 (A), SW20.2 (ROW)
unnamed: D21.2 (A), SW21.2 (ROW)
unnamed: D22.2 (A), SW22.2 (ROW)
unnamed: D23.2 (A), SW23.2 (ROW)
unnamed: D24.2 (A), SW24.2 (ROW)
unnamed: D25.2 (A), SW25.2 (ROW)
unnamed: D26.2 (A), SW26.2 (ROW)
unnamed: D27.2 (A), SW27.2 (ROW)
unnamed: D28.2 (A), SW28.2 (ROW)
unnamed: D29.2 (A), SW29.2 (ROW)
unnamed: D30.2 (A), SW30.2 (ROW)
unnamed: D31.2 (A), SW31.2 (ROW)
unnamed: D32.2 (A), SW32.2 (ROW)
unnamed: D33.2 (A), SW33.2 (ROW)
unnamed: D34.2 (A), SW34.2 (ROW)
RAW: SW_POWER0.3 (C), U1.24 (BATIN/P0.04)
RESET: RSW0.2, U1.22 (RST)
ROW0: D1.1 (K), D2.1 (K), D3.1 (K), D4.1 (K), D5.1 (K), U1.9 (P1.00)
ROW1: D6.1 (K), D7.1 (K), D8.1 (K), D9.1 (K), D10.1 (K), U1.10 (P0.11)
ROW2: D11.1 (K), D12.1 (K), D13.1 (K), D14.1 (K), D15.1 (K), U1.11 (P1.04)
ROW3: D16.1 (K), D17.1 (K), U1.12 (P1.06)
R_3V3: Display2.3 (VCC), U2.21 (VCC)
R_BT+: Bat+1.1, SW_POWER1.2 (B)
R_COL0: SW18.1 (COL), SW23.1 (COL), SW28.1 (COL), SW33.1 (COL), U2.8 (P0.24)
R_COL1: SW19.1 (COL), SW24.1 (COL), SW29.1 (COL), SW34.1 (COL), U2.9 (P1.00)
R_COL2: SW20.1 (COL), SW25.1 (COL), SW30.1 (COL), U2.10 (P0.11)
R_COL3: SW21.1 (COL), SW26.1 (COL), SW31.1 (COL), U2.11 (P1.04)
R_COL4: SW22.1 (COL), SW27.1 (COL), SW32.1 (COL), U2.12 (P1.06)
R_GND: BatGND1.1, Display2.4 (GND), RSW1.1, U2.3 (GND), U2.4 (GND), U2.23 (GND)
R_MOSI: Display2.1 (MOSI), U2.5 (P0.17)
R_NVCS: Display2.5 (CS), U2.1 (TX0/P0.06)
R_RAW: SW_POWER1.3 (C), U2.24 (BATIN/P0.04)
R_RESET: RSW1.2, U2.22 (RST)
R_ROW0: D18.1 (K), D19.1 (K), D20.1 (K), D21.1 (K), D22.1 (K), U2.16 (P1.13)
R_ROW1: D23.1 (K), D24.1 (K), D25.1 (K), D26.1 (K), D27.1 (K), U2.15 (P1.11)
R_ROW2: D28.1 (K), D29.1 (K), D30.1 (K), D31.1 (K), D32.1 (K), U2.14 (NFC2/P0.10)
R_ROW3: D33.1 (K), D34.1 (K), U2.13 (NFC1/P0.09)
R_SCK: Display2.2 (SCK), U2.6 (P0.20)
SCK: Display1.2 (SCK), U1.6 (P0.20)

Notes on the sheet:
Right Side (peripheral)
Battery "Business"
Left Side (main)

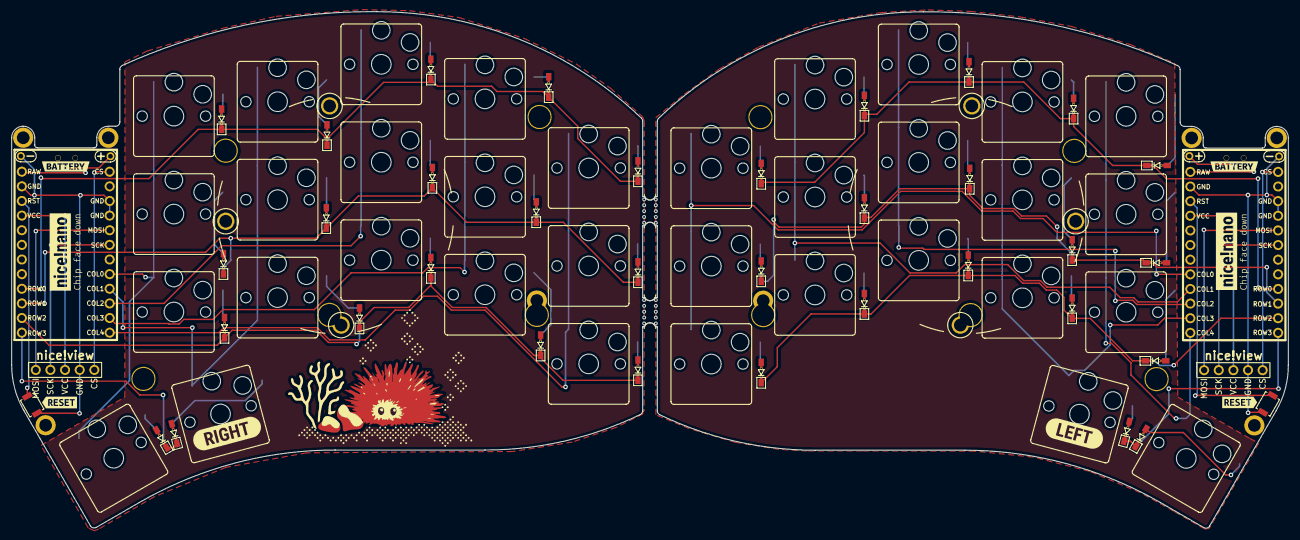
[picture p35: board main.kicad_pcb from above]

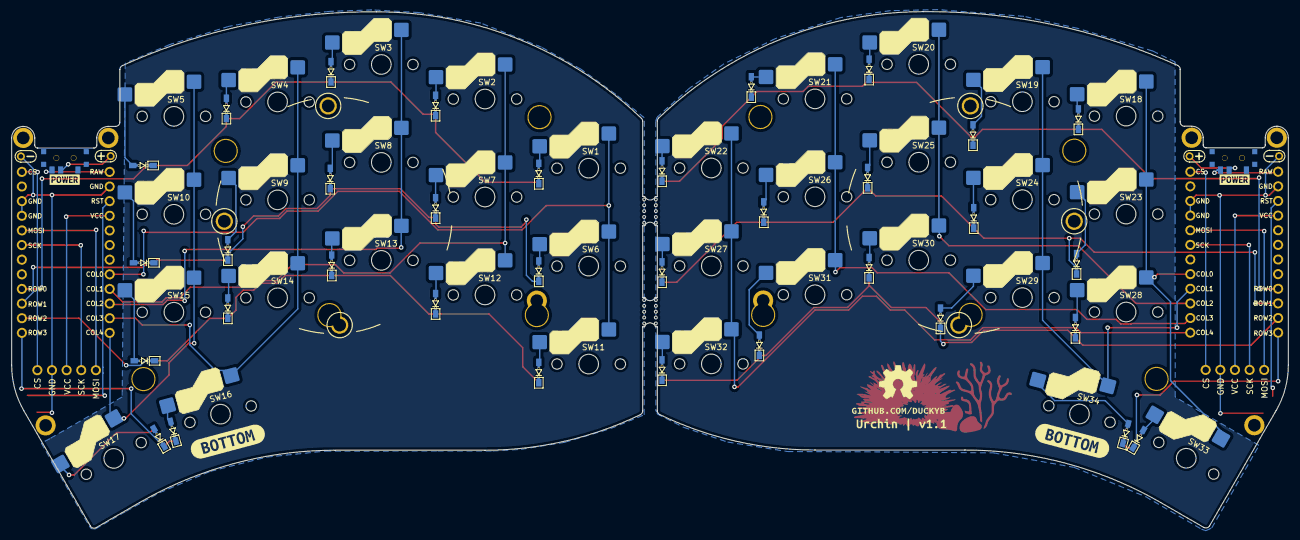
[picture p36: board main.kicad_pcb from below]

Board: 2 copper layers, 221.6 x 89.6 mm, 118 parts (20 on the bottom side), 68 nets.

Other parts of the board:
H1, H1#2, H2, H2#2, H3, H3#2, H4, H4#2, H4#3, H4#4: M2 Hole; M2_hole_4.2mm
REF_PUCK_R: Tenting Puck; Tenting_Puck2_no_pads
REF_PUCK_R#2: Tenting Puck; Tenting_Puck2_no_pads
Ref**: Val**; M2_hole_3.5mm
Ref**#2, Ref**#3, Ref**#4, Ref**#5, Ref**#6, Ref**#7, Ref**#8: Val**; M2_hole_3.5mm
kibuzzard-67E186E9: G***; kibuzzard-67E186E9
kibuzzard-636588C8, kibuzzard-636588C8#2: G***; kibuzzard-636588C8
kibuzzard-636592CC: G***; kibuzzard-636592CC
kibuzzard-6361375E, kibuzzard-6361375E#2: G***; kibuzzard-6361375E
kibuzzard-6365884B: G***; kibuzzard-6365884B
kibuzzard-6365950B: G***; kibuzzard-6365950B
kibuzzard-6365951E: G***; kibuzzard-6365951E
kibuzzard-63658823: G***; kibuzzard-63658823
kibuzzard-63658830: G***; kibuzzard-63658830
kibuzzard-63658865: G***; kibuzzard-63658865
kibuzzard-63659296: G***; kibuzzard-63659296
kibuzzard-63659328: G***; kibuzzard-63659328
kibuzzard-63659465: G***; kibuzzard-63659465
kibuzzard-63659477: G***; kibuzzard-63659477
mouse-bite-2mm-slot, mouse-bite-2mm-slot#2: VAL**; mouse-bite-5mm-slot-with-space-for-track

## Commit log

2022-11-01 Upload initial design
    [nice-sweep.kicad_pcb, nice-sweep.kicad_sch]
2022-11-01 Fix nice!nano orientation & add labels
    [nice-sweep.kicad_pcb, nice-sweep.kicad_sch]
2022-11-02 Update PCB with missing components
    [nice-sweep.kicad_pcb, nice-sweep.kicad_sch]
2022-11-02 Update silkscreens
    [nice-sweep.kicad_pcb]
2022-11-03 Rename files
    [main.kicad_pcb, main.kicad_sch]
2022-11-03 Update switch footprint
    [main.kicad_pcb]
2022-11-03 Add puck & update art silk
    [main.kicad_pcb]
2022-11-03 Remove references from silkscreen
    [main.kicad_pcb]
2022-11-03 Add copper fill under artwork footprint
    [main.kicad_pcb]
2022-11-04 Update silkscreen & fix DRC
    [main.kicad_pcb]
2022-11-06 Add artwork by Kneecrust
    [main.kicad_pcb]
2022-11-10 Make puck screw holes PTH
    [main.kicad_pcb]
2022-11-13 Update PCB silk
    [main.kicad_pcb]
2022-11-27 Add power switch to requirements
2023-03-18 Add 3d case
    [case-left.step, case-left.stl, case-right.step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]
2023-03-20 Refactor folder structure and add README
    [case-left.step, case-left.stl, case-right.step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]
2023-03-20 Add chewiedies case preview
2023-03-23 Add source file for chewiedies case
    [Urchin_Tray_Case.f3d]
2023-03-25 Use local library only
    [Urchin_Tray_Case.f3d, main.kicad_pcb, main.kicad_sch]
2024-06-17 add 3d files and update proj readme
    [Urchin Plate Case.f3z, Urchin Plate Case.step, urchin_case_left.stl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]
2024-06-17 update case readme
2024-08-05 Added switch and base plates
    [base-plate.kicad_pcb, switch-plate.kicad_pcb]
2024-08-07 Added plate gallery
2024-11-27 Add switch plate options
    [ALL-OPTIONS.3mf, fishbone__plate.stl, skeleton__plate.stl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]
2024-11-29 Add screen shield files
    [screen-shield.stl]
2024-11-29 Include dxf
    [screen-shield.dxf]
2025-01-15 added case-by-rayreside
    [case v8.step, screen-shield v16.step]
2025-01-15 added readme to case-by-rayreside
2025-02-14 Coral case launch
    [main.step]
2025-02-18 Add coral case render
2025-03-24 Fix wrong col/row labels for right half
    [main.kicad_pcb]
2025-03-24 Update Kibot -> KiCad_8
2025-03-24 Update version number silk
    [main.kicad_pcb]
2026-08-28 Add boxy case by rayreside
    [urchin_boxy_bottom_right.stl, urchin_boxy_mountains_right.stl, urchin_boxy_shield_right.stl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]
2026-09-27 Add tenting bottom case with TOTEM feet
    Replacement bottom for the Coral case that takes TOTEM-style tenting
    feet and leaves room for a 31x23x3 mm battery. Closes #23.
    [urchin_tenting_bottom_left.stl, urchin_tenting_bottom_right.stl]
2026-10-02 tenting bottom: print notes and photo of the printed part
